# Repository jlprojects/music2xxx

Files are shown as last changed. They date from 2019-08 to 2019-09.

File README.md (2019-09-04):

# music2xxx
## Hybrid Music 2000 Clone Midi I/O PCB

This is a hardware clone of the Hybrid Music 2000 Midi add-on for the Acorn BBC Microcomputer model B and Master 128 designed for use with the Hybrid Music 5000 system. It is designed to stack on the Music5xxx clone PCB, and uses the 5V supply from the main board. If used independently of the Music5xxx, you will need to provide a 5V supply - this can come from the BBC Micro's auxiliary power connector.

The Music 2000 Midi interface combined with the AMPLE programming language and the Hybrid Studio 5000 Studio software provides versatile control of external Midi devices. The Music 2000 has 3 Midi output sockets.

Despite having an on-board Midi input port, AMPLE and the Hybrid System cannot use it directly. It is assumed that the Hybrid system is used as a controller and sequencer. However, it is possible to address the interface from user programs.

## The clone
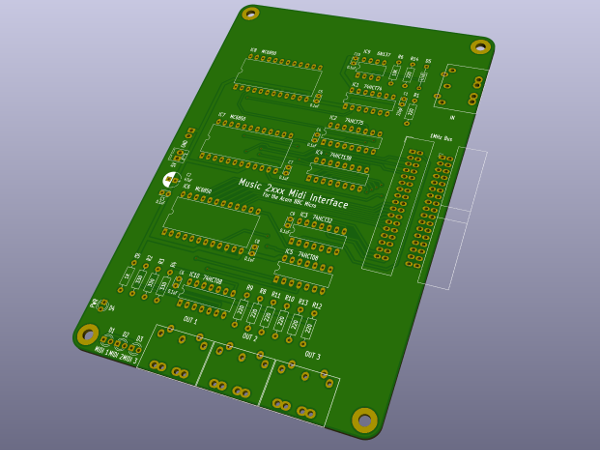
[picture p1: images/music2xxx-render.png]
music5xxx PCB render


It is designed in Kicad, based upon Colin Fraser's reverse-engineered schematic. http://www.colinfraser.com/m5000/m2000sch.pdf This version uses a different opto-isolator on the Midi input, and implements activity LEDs for the Midi outputs. 

Currently all the 74xx series logic ICs are available new. The 6850 UART ICs are no longer manufactured, but are commonly available second-hand or new-old-stock. 

4/9/19 For standalone use, an optional LM7805 regulator is added to allow powering the board from 9V-12V, as well as an LED to show input activity. A few prototype PCBs have been ordered.

## Using outside the Hybrid system

It's possible to use the m2000 Midi interface in BASIC or machine code - the 6850 Uarts can be read to or written to at addresses: 

* FC08/9 ACIA 1 (MIDI OUT 1)
* FC0A/B ACIA 2 (MIDI OUT 2)
* FC0C/D ACIA 3 (MIDI OUT 3, MIDI IN)

Info from: http://mdfs.net/Info/Comp/BBC/MIDI/m2000

## Resources

* Colin Fraser's Music5000 Resources: http://www.colinfraser.com/m5000/m5000.htm

* The Music2000 Interface User Guide covers all aspects of controlling Midi instruments with AMPLE and Studio 5000. It's available on the retro-kit archive page describing the Hybrid Music 2000: https://www.retro-kit.co.uk/page.cfm/content/Hybrid-Music-2000-Interface/

* A comprehensive archive about the Hybrid Music System: https://www.retro-kit.co.uk/page.cfm/content/Hybrid-Music-5000-Synthesiser/

* Here's the Stardot thread about this project: https://stardot.org.uk/forums/viewtopic.php?f=3&t=16895

* The Stardot 8bit hardware forum often has posts about the Hybrid Music system: https://stardot.org.uk/forums/viewforum.php?f=3

* Information about Midi on the BBC Microcomputer: http://mdfs.net/Info/Comp/BBC/MIDI/

## Licence

Unless otherwise marked, work in this repository is licenced under [Creative Commons Attribution-ShareAlike 4.0 International License](http://creativecommons.org/licenses/by-sa/4.0/)

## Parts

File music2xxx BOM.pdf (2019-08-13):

music2xxx

## Music2xxx PCB BOM

Quantity | Designation | Designator | Notes

Resistors
8 | 220
3 | 330 | R2, R3, R4
1 | 1K | R5
1 | 10K | R6

Capacitors
1 | 220pF | C1 | Ceramic: 2.5mm lead pitch
1 | 47uF | C2 | Electrolytic 2.5mm lead pitch
8 | 0.1uF | | Ceramic: 2.5mm lead pitch

Diodes
1 | 1n4148 | D5 | Do-35 standard diode
3 | LED | D1, D2, D3, D4 | 3mm LED

Integrated Circuits
2 | 74HCT08 | IC5, IC10
1 | 74HCT32 | IC3
1 | 74HCT74 | IC1
1 | 74HCT75 | IC2
1 | 74HCT138 | IC4
1 | 6N137 | IC9
3 | MC6850 | IC6, IC7, IC8 | 6850 UART – buy NOS

IC Sockets
1 | 8 Way | 7.62mm wide
4 | 14 Way | 7.62mm wide
2 | 16 Way | 7.62mm wide
3 | 24 Way | 15.24mm Wide

Connectors
4 | 5 Way din socket | J5, J6, J7, J8 | 180 degree PCB mount
1 | 1MHzBus1 | J1
1 | 1MHzBus2 | J2
2 | 2 Way Molex KK or similar J3, J4 | 5V Power input

R1, R8, R9, R10, R11, R12, R13, R14

Standard 1% metal film through hole resistors

C3, C4, C5, C6, C7, C8, C9, C10

34 way (2x17) 2.54mm Straight IDC Header (optional)
34 way (2x17) 2.54mm Angled IDC Header for 1Mhz Bus connection

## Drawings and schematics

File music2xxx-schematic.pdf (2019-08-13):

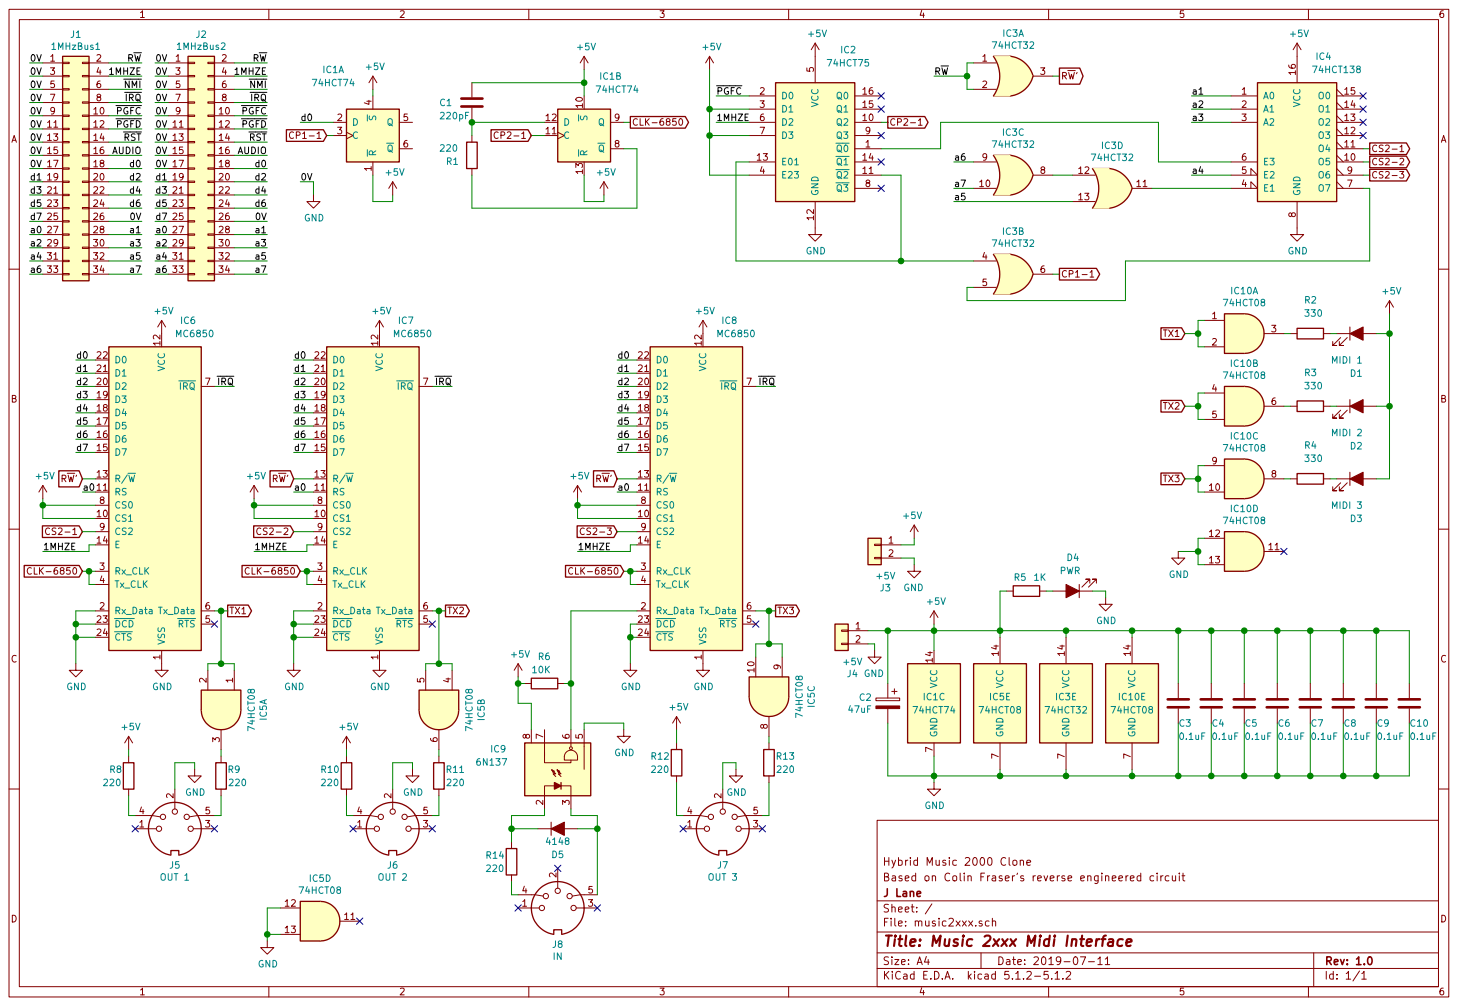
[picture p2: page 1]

File: music2xxx.sch Sheet: / J Lane Based on Colin Fraser's reverse engineered circuit

Id: 1/1 Title: Music 2xxx Midi Interface

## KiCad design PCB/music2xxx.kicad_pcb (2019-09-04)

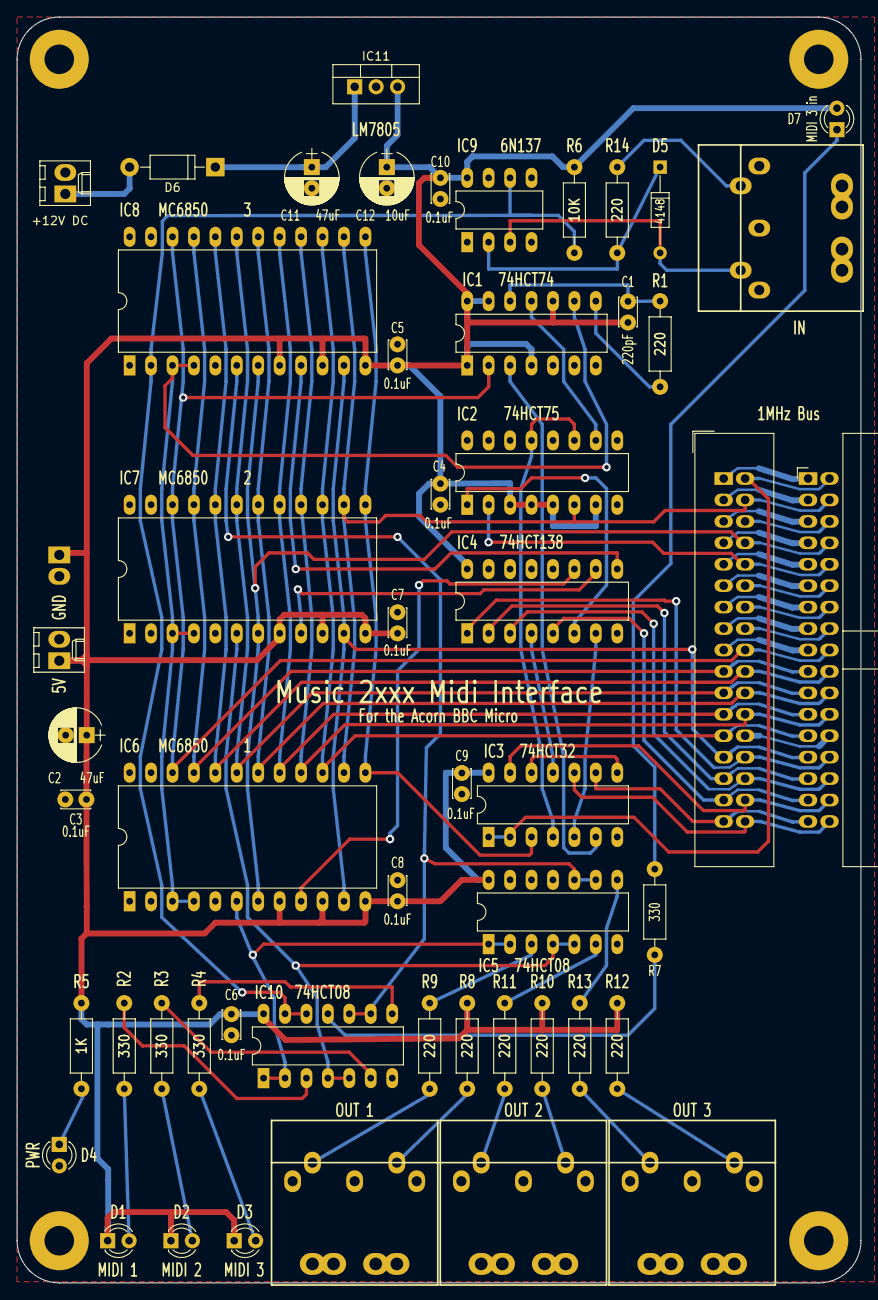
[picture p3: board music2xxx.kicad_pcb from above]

Board: 2 copper layers, 100.0 x 150.0 mm, 57 parts (1 on the bottom side), 67 nets.

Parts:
C1: 220pF; C_Disc_D3.4mm_W2.1mm_P2.50mm
C2, C11: 47uF; CP_Radial_D6.3mm_P2.50mm
C3, C4, C5, C6, C7, C8, C9, C10: 0.1uF; C_Disc_D3.4mm_W2.1mm_P2.50mm
C12: 10uF; CP_Radial_D6.3mm_P2.50mm
D1: MIDI 1; LED_D3.0mm
D2: MIDI 2; LED_D3.0mm
D3: MIDI 3; LED_D3.0mm
D4: PWR; LED_D3.0mm
D5: 4148; D_DO-35_SOD27_P10.16mm_Horizontal
D6: 1N4001; D_DO-41_SOD81_P10.16mm_Horizontal
D7: MIDI 3 in; LED_D3.0mm
H1, H2, H3, H4: 3.5mm; MountingHole_3.5mm_Pad
IC1: 74HCT74; DIP-14_W7.62mm_LongPads
IC2: 74HCT75; DIP-16_W7.62mm_LongPads
IC3: 74HCT32; DIP-14_W7.62mm_LongPads
IC4: 74HCT138; DIP-16_W7.62mm_LongPads
IC5, IC10: 74HCT08; DIP-14_W7.62mm_LongPads
IC6, IC7, IC8: MC6850; DIP-24_W15.24mm_LongPads
IC9: 6N137; DIP-8_W7.62mm_LongPads
IC11: LM7805_TO220; TO-220-3_Vertical
J1: 1MHzBus1; IDC-Header_2x17_Pitch2.54mm_Angled
J2: 1MHzBus2; IDC-Header_2x17_Pitch2.54mm_Straight
J3, J4: +5V; Molex_KK-6410-02_02x2.54mm_Straight
J5: OUT 1; din_5_pcb_mount
J6: OUT 2; din_5_pcb_mount
J7: OUT 3; din_5_pcb_mount
J8: IN; din_5_pcb_mount
J9: +12V DC; Molex_KK-6410-02_02x2.54mm_Straight
R1, R8, R9, R10, R11, R12, R13, R14: 220; R_Axial_DIN0207_L6.3mm_D2.5mm_P10.16mm_Horizontal
R2, R3, R4, R7: 330; R_Axial_DIN0207_L6.3mm_D2.5mm_P10.16mm_Horizontal
R5: 1K; R_Axial_DIN0207_L6.3mm_D2.5mm_P10.16mm_Horizontal
R6: 10K; R_Axial_DIN0207_L6.3mm_D2.5mm_P10.16mm_Horizontal

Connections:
+5V: C1.1, C2.1, C3.1, C4.1, C5.1, C6.1, C7.1, C8.1, C9.1, C10.1, C12.1, D1.2, D2.2, D3.2, D7.2, IC1.1, IC1.4, IC1.10, IC1.13, IC1.14, IC2.3, IC2.4, IC2.5, IC2.7, IC3.14, IC4.16, IC5.14, IC6.8, IC6.10, IC6.12, IC7.8, IC7.10, IC7.12, IC8.8, IC8.10, IC8.12, IC9.8, IC10.14, IC11.3, J3.1, J4.1, R5.1, R6.2, R8.1, R10.1, R12.1
/1MHZE: IC2.6, IC6.14, IC7.14, IC8.14, J1.4, J2.4
/AUDIO: J1.16, J2.16
/R~W: IC3.1, IC3.2, J1.2, J2.2
/a0: IC6.11, IC7.11, IC8.11, J1.27, J2.27
/a1: IC4.1, J1.28, J2.28
/a2: IC4.2, J1.29, J2.29
/a3: IC4.3, J1.30, J2.30
/a4: IC4.5, J1.31, J2.31
/a5: IC3.13, J1.32, J2.32
/a6: IC3.9, J1.33, J2.33
/a7: IC3.10, J1.34, J2.34
/d0: IC1.2, IC6.22, IC7.22, IC8.22, J1.18, J2.18
/d1: IC6.21, IC7.21, IC8.21, J1.19, J2.19
/d2: IC6.20, IC7.20, IC8.20, J1.20, J2.20
/d3: IC6.19, IC7.19, IC8.19, J1.21, J2.21
/d4: IC6.18, IC7.18, IC8.18, J1.22, J2.22
/d5: IC6.17, IC7.17, IC8.17, J1.23, J2.23
/d6: IC6.16, IC7.16, IC8.16, J1.24, J2.24
/d7: IC6.15, IC7.15, IC8.15, J1.25, J2.25
/~IRQ: IC6.7, IC7.7, IC8.7, J1.8, J2.8
/~NMI: J1.6, J2.6
/~PGFC: IC2.2, J1.10, J2.10
/~PGFD: J1.12, J2.12
/~RST: J1.14, J2.14
CLK-6850: IC1.9, IC6.3, IC6.4, IC7.3, IC7.4, IC8.3, IC8.4
CP1-1: IC1.3, IC3.6
CP2-1: IC1.11, IC2.10
CS2-1: IC4.11, IC6.9
CS2-2: IC4.10, IC7.9
CS2-3: IC4.9, IC8.9
GND: C2.2, C3.2, C4.2, C5.2, C6.2, C7.2, C8.2, C9.2, C10.2, C11.2, C12.2, D4.1, IC1.7, IC2.12, IC3.7, IC4.8, IC5.7, IC5.12, IC5.13, IC6.1, IC6.2, IC6.23, IC6.24, IC7.1, IC7.2, IC7.23, IC7.24, IC8.1, IC8.23, IC8.24, IC9.5, IC10.7, IC11.2, J1.1, J1.3, J1.5, J1.7, J1.9, J1.11, J1.13, J1.15, J1.17, J1.26, J2.1, J2.3, J2.5, J2.7, J2.9, J2.11, J2.13, J2.15, J2.17, J2.26, J3.2, J4.2, J5.2, J6.2, J7.2, J9.2
unnamed: C1.2, IC1.12, R1.2
unnamed: C11.1, D6.1, IC11.1
unnamed: D1.1, R2.2
unnamed: D2.1, R3.2
unnamed: D3.1, R4.2
unnamed: D4.2, R5.2
unnamed: D5.1, IC9.2, R14.1
unnamed: D5.2, IC9.3, J8.5
unnamed: D6.2, J9.1
unnamed: D7.1, R7.2
unnamed: IC1.8, R1.1
unnamed: IC2.1, IC4.6
unnamed: IC2.11, IC2.13, IC3.4
unnamed: IC3.5, IC4.7
unnamed: IC3.11, IC4.4
unnamed: IC3.8, IC3.12
unnamed: IC5.3, R9.1
unnamed: IC5.6, R11.1
unnamed: IC5.8, R13.1
unnamed: IC10.3, R2.1
unnamed: IC10.6, R3.1
unnamed: IC10.8, R4.1
unnamed: IC10.11, R7.1
unnamed: J5.4, R8.2
unnamed: J5.5, R9.2
unnamed: J6.4, R10.2
unnamed: J6.5, R11.2
unnamed: J7.4, R12.2
unnamed: J7.5, R13.2
unnamed: J8.4, R14.2
RX3: IC8.2, IC9.6, IC10.12, IC10.13, R6.1
R~W~': IC3.3, IC6.13, IC7.13, IC8.13
TX1: IC5.1, IC5.2, IC6.6, IC10.1, IC10.2
TX2: IC5.4, IC5.5, IC7.6, IC10.4, IC10.5
TX3: IC5.9, IC5.10, IC8.6, IC10.9, IC10.10
